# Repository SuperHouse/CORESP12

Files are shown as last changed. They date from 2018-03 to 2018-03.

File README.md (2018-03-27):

CoreSP12 ESP8266 Board
======================
Copyright 2015 SuperHouse Automation Pty Ltd <http://www.superhouse.tv>  

An ESP8266 module with the same footprint as a Spark Core or Particle
Photon, so that it can be a drop-in replacement for some projects.

Note: only a subset of the Core's I/O pins are connected, so this will
only work for projects that specifically use those pins. There are
many other limitations so use at your own risk!

More information is available at:

  http://www.superhouse.tv/coresp12

INSTALLATION
------------
The design is saved as an EAGLE project. EAGLE PCB design software is
available from www.cadsoftusa.com free for non-commercial use. To use
this project download it and place the directory containing these files
into the "eagle" directory on your computer. Then open EAGLE and
navigate to the project.

DISTRIBUTION
------------
The specific terms of distribution of this project are governed by the
license referenced below.

LICENSE
-------
Licensed under the TAPR Open Hardware License (www.tapr.org/OHL).
The "license" folder within this repository also contains a copy of
this license in plain text format.

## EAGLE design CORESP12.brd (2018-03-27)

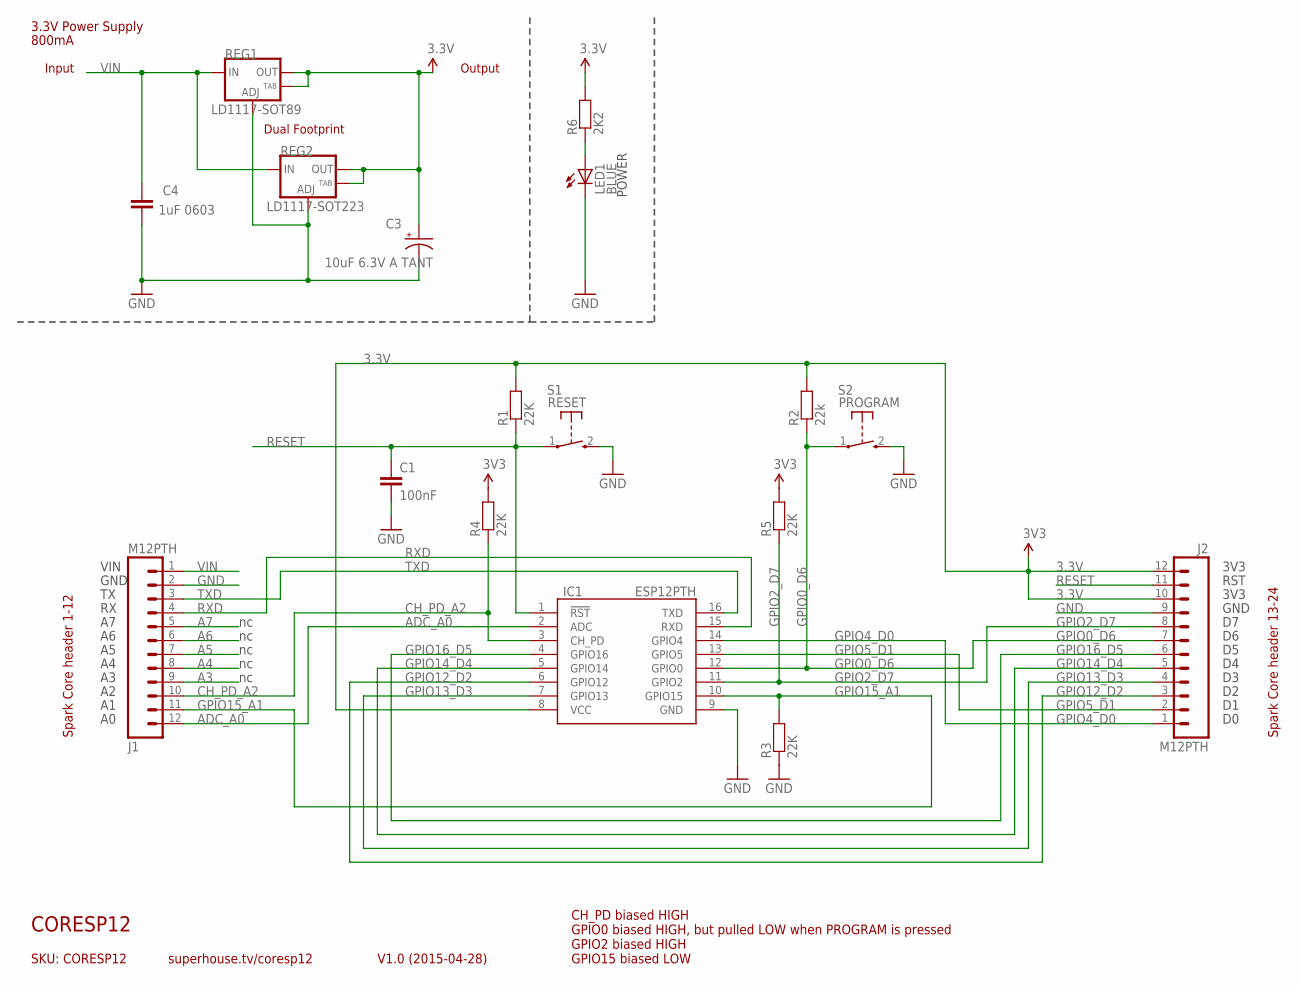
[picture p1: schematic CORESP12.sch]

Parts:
C1: 100nF; 0603
C3: 10uF 6.3V A TANT; EIA3216
C4: 1uF 0603; 0603
IC1: ESP12PTH
J1, J2: M12PTH; 1X12
LED1: BLUE; LED-0603
R1, R3, R4, R5: 22K; 0603
R2: 22k; 0603
R6: 2K2; 0603
REG1: LD1117-SOT89; SOT89
REG2: LD1117-SOT223; SOT223
S1: RESET; TACTILE_SWITCH_SMD_2PIN_TINY
S2: PROGRAM; TACTILE_SWITCH_SMD_2PIN_TINY

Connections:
3.3V: C3.A (+), IC1.8 (VCC), J2.10, J2.12, R1.2, R2.2, R4.2, R5.2, R6.2, REG1.2 (OUT), REG1.4 (OUT), REG2.2 (OUT), REG2.4 (OUT)
A3: J1.9
A4: J1.8
A5: J1.7
A6: J1.6
A7: J1.5
ADC_A0: IC1.2 (ADC), J1.12
CH_PD_A2: IC1.3 (CH_PD), J1.10, R4.1
GND: C1.2, C3.C (-), C4.2, IC1.9 (GND), J1.2, J2.9, LED1.C, R3.1, REG1.1 (ADJ), REG2.1 (ADJ), S1.2 (S), S2.2 (S)
GPIO0_D6: IC1.12 (GPIO0), J2.7, R2.1, S2.1
GPIO2_D7: IC1.11 (GPIO2), J2.8, R5.1
GPIO4_D0: IC1.14 (GPIO4), J2.1
GPIO5_D1: IC1.13 (GPIO5), J2.2
GPIO12_D2: IC1.6 (GPIO12), J2.3
GPIO13_D3: IC1.7 (GPIO13), J2.4
GPIO14_D4: IC1.5 (GPIO14), J2.5
GPIO15_A1: IC1.10 (GPIO15), J1.11, R3.2
GPIO16_D5: IC1.4 (GPIO16), J2.6
unnamed: LED1.A, R6.1
RESET: C1.1, IC1.1 (!RST), J2.11, R1.1, S1.1
RXD: IC1.15 (RXD), J1.4
TXD: IC1.16 (TXD), J1.3
VIN: C4.1, J1.1, REG1.3 (IN), REG2.3 (IN)

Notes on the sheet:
SKU: CORESP12
CORESP12
V1.0 (2015-04-28)
superhouse.tv/coresp12
CH_PD biased HIGH GPIO0 biased HIGH, but pulled LOW when PROGRAM is pressed GPIO2 biased HIGH GPIO15 biased LOW
3.3V Power Supply
Output
Input
POWER
Dual Footprint
800mA
Spark Core header 1-12
Spark Core header 13-24
VIN
GND
3V3
RST

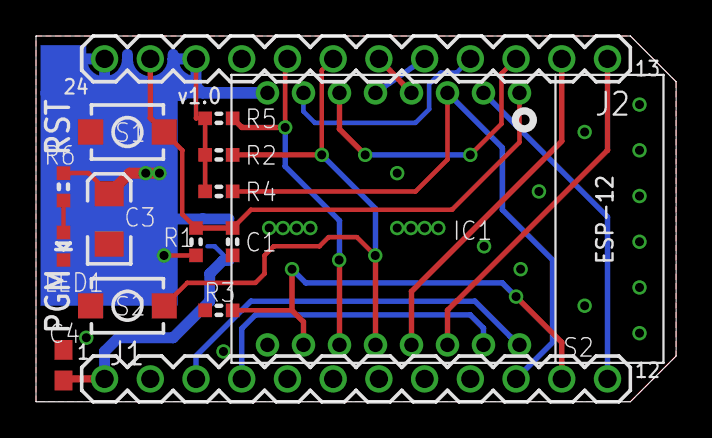
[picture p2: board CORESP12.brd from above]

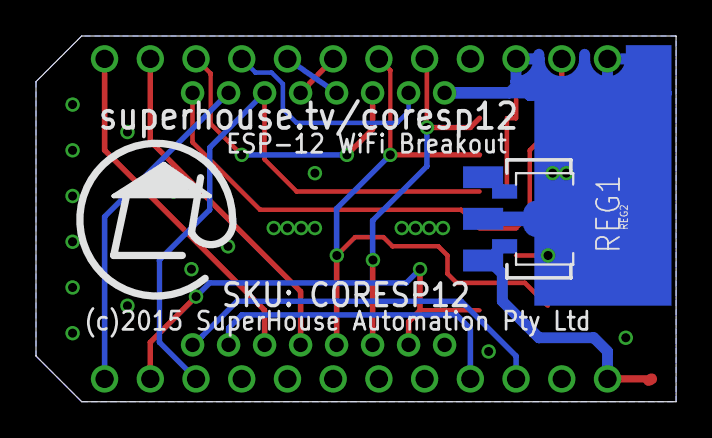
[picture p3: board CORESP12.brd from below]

Board: 2 copper layers, 35.6 x 20.3 mm, 17 parts (2 on the bottom side), 18 nets.

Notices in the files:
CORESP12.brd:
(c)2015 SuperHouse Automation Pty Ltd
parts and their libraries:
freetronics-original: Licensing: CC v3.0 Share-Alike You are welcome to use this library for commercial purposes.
